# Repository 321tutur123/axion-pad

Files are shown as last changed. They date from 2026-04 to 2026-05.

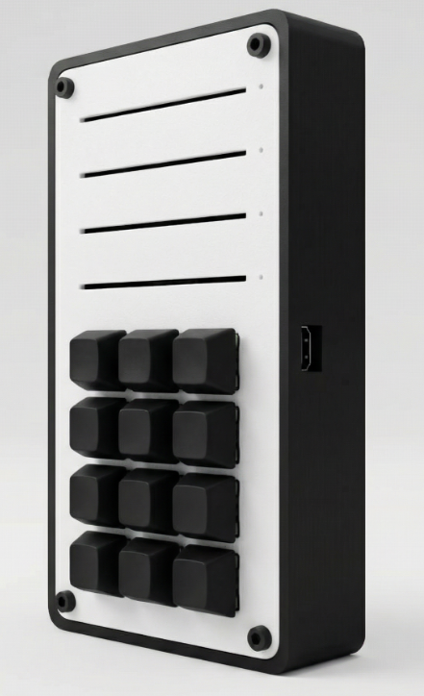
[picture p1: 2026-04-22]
assets/photos/vue du coté.png

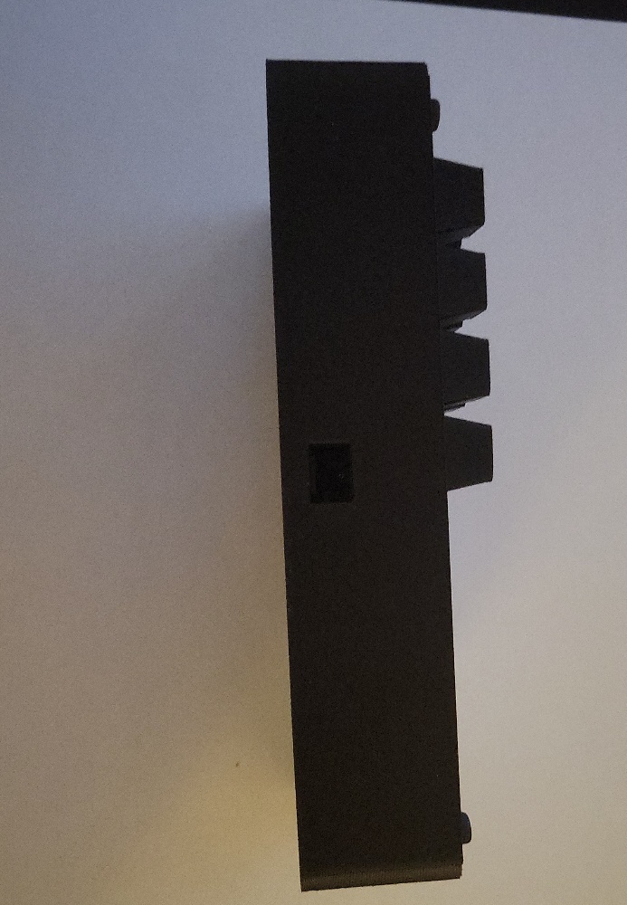
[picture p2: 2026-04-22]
assets/photos/derriere.jpg

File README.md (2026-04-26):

# AxionPad

**The macro pad built for creators, streamers, and power users.**  
Map macros, control audio, and fine-tune every detail — all from one device.

→ **[axionpad.fr](https://axionpad.fr)**

---

## The Product

AxionPad is a compact, programmable macro pad powered by an RP2040 microcontroller. It comes in three versions to match every setup:

| Model | Keys | Faders | RGB | OLED |
|---|---|---|---|---|
| **Mini** | 6 | — | Optional | — |
| **Standard** | 12 | 4 | Optional | — |
| **XL** | 16 | 6 | Optional | Yes|

All models ship with the **AxionPad Native** configurator for Windows.

---

## AxionPad Native — Configurator App

The desktop companion app lets you configure every key and fader without touching any code. Changes are pushed directly to the device over USB.

**Download:** [Latest Release](https://github.com/321tutur123/axion-pad/releases/latest) — Windows `.exe` installer

### Key features

- **Macro keys** — keyboard shortcuts, app launch, media controls, mute targets, AutoHotkey scripts
- **Audio faders** — per-process volume control via WASAPI (no virtual audio drivers needed)
- **RGB control** — per-key color and lighting effects
- **OLED display** (XL only) — live system stats or custom text
- **Presets** — Streaming, Gaming, Productivity, DAW — switch in one click
- **Live soundbar** — real-time visualization of fader values
- **System tray** — runs silently in the background, auto-starts with Windows
- **Direct flash** — exports `code.py` and writes it straight to the device's `CIRCUITPY` drive

---

## Repository Structure

```
axion-pad/
├── application/      Java/JavaFX configurator (Maven)
├── firmwares/
│   ├── MINI/         CircuitPython firmware — Mini
│   ├── STANDARD/     CircuitPython firmware — Standard
│   └── XL/           CircuitPython firmware — XL
├── hardware/
│   ├── pcb/          PCB schematics
│   └── cad/          3D models (STL / OBJ)
├── website/          Next.js landing page → axionpad.fr (Cloudflare Pages)
└── assets/           Brand assets (logos, photos)
```

---

## Tech Stack

| Layer | Technology |
|---|---|
| Microcontroller | RP2040 + CircuitPython |
| Desktop app | Java 17, JavaFX 21, Maven |
| Serial I/O | jSerialComm |
| Windows audio | WASAPI via JNA |
| Website | Next.js 15, Tailwind CSS |
| Hosting | Cloudflare Pages |
| CI/CD | GitHub Actions |

---

## Building from Source

### Prerequisites

- Java 17+
- Maven 3.8+

### Run in dev mode

```bash
cd application
mvn javafx:run
```

### Build Windows installer

```bash
cd application
scripts\build-windows.bat
# Output: dist/windows/AxionPadConfigurator.exe
```

---

## Website — Cloudflare Pages

Every push to `main` that touches `website/**` triggers an automatic deployment via GitHub Actions.

### Required secrets

| Secret | Description |
|---|---|
| `CLOUDFLARE_API_TOKEN` | API token with *Cloudflare Pages: Edit* permission |
| `CLOUDFLARE_ACCOUNT_ID` | Found in the Cloudflare dashboard sidebar |

---

## License

The configurator source code is released under the **MIT License**.  
The AxionPad name, logo, and hardware designs are proprietary — all rights reserved.

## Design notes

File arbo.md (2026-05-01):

# Arborescence du projet AxionPad

> Projet : macro pad programmable (RP2040 + CircuitPython) avec configurateur JavaFX et site e-commerce Next.js.

---

## Racine du projet

| Fichier | Rôle |
|---|---|
| `README.md` | Documentation principale : présentation du produit, versions (Mini/Standard/XL), stack technique, instructions de build |
| `.gitignore` | Fichiers et dossiers exclus du suivi Git |
| `RECAP_PROJET.txt` | Résumé global du projet |

## Maintenance updates for version 2.0.3:

### Dynamic Slider Support (DeviceModel.java, SliderConfig.java)
- Added full support for 6 sliders on XL model (GP0/A4 and GP1/A5 pins)
- Safe pin label access with bounds checking
- Improved Python/YAML export formatting with validation

### Audio Service Improvements (WindowsVolumeService.java)
- Enhanced process mute handling with .exe suffix enforcement
- Added special Discord mute case
- Throttled error logging to prevent spam
- Unified logging through DebugLogger

### Logging Refactor (KeysController.java, Main.java)
- Removed all debug() calls in favor of DebugLogger
- Added proper error handling around serial operations  
- Centralized logging configuration in DebugLogger
- Removed hardcoded temp file paths

### JSON Handling (OpenRgbServer.java)
- Added robust JSON validation and error handling
- Proper type checking for all input fields
- Input sanitization for RGB values
- Standardized error responses

### Build System (build-windows.bat, pom.xml)
- Version bumped to 2.0.3
- Fixed BOM encoding issues in build script
- Cleaned up debug artifacts
- Improved build reliability

### Documentation
- Updated all code documentation
- Standardized logging messages across services
- Added architecture notes for audio and RGB services
| `arbo.md` | Ce fichier — cartographie complète de l'arborescence |
| `axion-pad.*.log` | Log d'exécution de l'application (généré automatiquement) |
| `.aider.chat.history.md` | Historique de conversations avec l'IA Aider |
| `.aider.input.history` | Historique des commandes Aider |

---

## `.claude/` — Configuration Claude Code

| Fichier | Rôle |
|---|---|
| `settings.json` | Paramètres globaux Claude Code : serveur MCP filesystem, liste blanche de commandes (npm, git, bash) |
| `settings.local.json` | Surcharges locales non versionnées des paramètres Claude |

---

## `.github/workflows/` — CI/CD GitHub Actions

| Fichier | Rôle |
|---|---|
| `deploy.yml` | Pipeline de déploiement du site sur Cloudflare Pages (déclenché sur push dans `website/`, Node 22, `npm run pages:build`, wrangler-action) |
| `java-ci.yml` | Pipeline CI Java : compile et exécute les tests Maven (`mvn -B -q test`) sur Java 17 à chaque push/PR touchant `application/` |

---

## `application/` — Configurateur desktop JavaFX

Application de bureau Windows (Java 17 + JavaFX 21) qui permet de configurer le macro pad via USB série.

### Fichiers de build & config

| Fichier | Rôle |
|---|---|
| `pom.xml` | Fichier Maven : dépendances (JavaFX 21, jSerialComm, Gson, JNA), configuration du plugin jpackage pour générer le MSI |
| `build-windows.bat` | Script batch pour builder l'installeur MSI Windows |
| `build-unix.sh` | Script shell équivalent pour Linux/macOS |
| `icon.ico` | Icône de l'application |
| `CLAUDE.md` | Guide d'architecture interne pour Claude Code (pattern MVC, modèles matériels, flux de données) |
| `README.md` | Documentation technique détaillée : prérequis, connexion série, contrôle du volume, codes d'erreur, FAQ |
| `.claude/settings.local.json` | Surcharges Claude Code locales au sous-projet |

### `src/main/java/com/axionpad/` — Code source Java

#### Point d'entrée

| Fichier | Rôle |
|---|---|
| `Main.java` | Point d'entrée JVM ; initialise le logging vers `C:\temp\axionpad_debug.log` |
| `AxionPadApp.java` | Sous-classe `javafx.application.Application` ; démarre la fenêtre principale |
| `StartupRegistryHelper.java` | Interagit avec le registre Windows pour activer/désactiver le démarrage automatique au boot |

#### `view/` — Couche Vue (UI)

| Fichier | Rôle |
|---|---|
| `MainWindow.java` | Fenêtre racine : StackPane avec routing de navigation, sidebar, badge du modèle détecté |
| `PortDialog.java` | Dialogue de sélection du port série USB |

#### `controller/` — Couche Contrôleur (gestion des pages)

| Fichier | Rôle |
|---|---|
| `Controllers.java` | Registre central de tous les contrôleurs |
| `KeysController.java` | Grille de touches (6/12/16 selon le modèle) ; panneau de configuration par touche (ActionType : KEYBOARD, APP, MUTE, MEDIA, AHK) ; UI des modificateurs et raccourcis |
| `SlidersController.java` | Mapping des potentiomètres (0/4/6 canaux selon le modèle) ; noms des processus pour le contrôle du volume par application |
| `SoundbarController.java` | Visualisation en temps réel des niveaux sonores via `ProgressBar` |
| `RgbController.java` | Contrôle des LEDs RGB (effets : OFF/STATIC/BREATHING/WAVE, color pickers, vitesse, luminosité) — Standard/XL uniquement |
| `ExportController.java` | Affiche le code `code.py` généré pour le firmware ; fonctions copier/enregistrer |
| `SimulatorController.java` | Simulateur logiciel du périphérique (sans matériel réel) |
| `SettingsController.java` | Panneau des préférences de l'application |
| `PresetService.java` | Gestionnaire de presets intégrés (Streaming, Gaming, Productivité, MAO) |

#### `model/` — Couche Modèle (données)

| Fichier | Rôle |
|---|---|
| `DeviceModel.java` | Enum des modèles matériels : MINI (6 touches), STANDARD (12 touches + 4 pots), XL (16 touches + 6 pots + OLED). Auto-détecté depuis le greeting firmware |
| `KeyConfig.java` | Configuration d'une touche individuelle : ActionType, modificateurs, code touche, chemin d'application |
| `SliderConfig.java` | Configuration d'un canal potentiomètre : nom du processus, plage de volume |
| `RgbConfig.java` | Paramètres RGB : type d'effet, couleur1, couleur2, luminosité, vitesse |
| `PadConfig.java` | Configuration complète du pad : nom de profil, liste de layers, tableau sliders, config RGB. Rétrocompatible v1 |
| `AppSettings.java` | Paramètres applicatifs (démarrage auto, langue, etc.) |

#### `service/` — Couche Service (logique métier & matériel)

| Fichier | Rôle |
|---|---|
| `SerialService.java` | Gestion du port série via jSerialComm : auto-détection, détection du modèle depuis le greeting firmware, watchdog 5 s, basculement mode POLL selon minimisation de l'UI |
| `ConfigService.java` | Persistance JSON dans `~/.axionpad/config.json` ; migration rétrocompatible depuis la v1 |
| `WindowsVolumeService.java` | Contrôle audio WASAPI/COM via JNA sur thread STA dédié ; throttle à 20 Hz ; volume par application |
| `RgbService.java` | Persistance des effets LED et génération des commandes série (format `RGB:STATIC:r,g,b`) |
| `OledService.java` | Gestion de l'afficheur OLED du modèle XL : synchronisation RTC + stats périodiques CPU/RAM/heure toutes les 2 s |
| `OpenRgbServer.java` | Serveur HTTP REST sur `127.0.0.1:7742` pour l'intégration SignalRGB/OpenRGB ; CORS activé ; pool de threads asynchrone |
| `KeyHookService.java` | Enregistrement du hook clavier global Windows (capture bas niveau des touches) |
| `HardwareMonitorService.java` | Stats CPU/RAM via MXBean ; GPU/température stubés (nécessite OSHI/NVML) |
| `InventoryService.java` | Suivi de l'inventaire matériel |
| `AppLauncherService.java` | Lancement d'exécutables applicatifs |
| `SettingsService.java` | Persistance et récupération des paramètres |
| `I18n.java` | Chaînes d'internationalisation/localisation |
| `DebugLogger.java` | Logging vers `%APPDATA%/AxionPad/debug.log` |

### `src/main/resources/com/axionpad/`

| Chemin | Rôle |
|---|---|
| `css/dark.css` | Feuille de style unique — thème sombre de l'application |
| `firmware/code.py` | Copie embarquée du firmware STANDARD pour l'export in-app |
| `icons/axionpad_tray.png` | Icône de la barre système (tray) |
| `icons/icon.ico` | Icône de fenêtre |
| `icons/logo1.png` | Logo de l'application |

### `src/test/java/com/axionpad/model/` — Tests unitaires

| Fichier | Rôle |
|---|---|
| `DeviceModelTest.java` | Tests du modèle matériel (enum DeviceModel) |
| `PadConfigTest.java` | Tests de l'objet de configuration (sérialisation, migration v1→v2) |
| `SliderConfigTest.java` | Tests de la configuration des potentiomètres |

### `dist/` — Installeurs distribués

| Fichier | Rôle |
|---|---|
| `AxionPad-2.0.1.msi` | Installeur MSI version actuelle |
| `AxionPad-2.0.0.msi` | Version précédente |
| `AxionPad-1.0.1.msi` | Version legacy |
| `AxionPad-1.0.msi` | Version originale |

---

## `firmwares/` — Firmware CircuitPython (3 variantes)

Chaque variante émet un greeting `AXIONPAD:[MODELE]` au démarrage pour l'auto-détection par le configurateur.

| Fichier | Rôle |
|---|---|
| `MINI/code.py` | Firmware 6 touches (2×3), sans RGB ni OLED |
| `STANDARD/code.py` | Firmware 12 touches (3×4), 4 potentiomètres, LEDs RGB NeoPixel |
| `XL/code.py` | Firmware 16 touches (4×4), 6 potentiomètres, RGB NeoPixel, écran OLED SSD1306, module RTC |

**Protocole série :**
- Sortie : `"val1|val2|val3|val4\n"` pour les valeurs des sliders
- Entrée : `RGB:STATIC:r,g,b` · `POLL:LOW/HIGH` · `OLED[:CPU:XX][:RAM:XX][:HHMM:XXXX]`

---

## `hardware/` — Fichiers de conception matérielle

### `hardware/cad/body/` — Boîtier

| Fichier | Rôle |
|---|---|
| `Body_certo.SLDPRT` / `.STL` | Corps principal du boîtier (SolidWorks + export STL pour impression 3D) |
| `Top_Case_.SLDPRT` / `.STL` | Couvercle supérieur |
| `body axion v5.f3z` | Boîtier version 5 (Fusion 360) |
| `body axion v4.3.3mf` / `body axion.3mf` | Boîtier en format 3MF (impression 3D) |
| `v_perso axion.3mf` | Variante personnalisée |
| `alignement des touches v*.stl` | Gabarits d'alignement des touches (v1 et v2) |
| `dessus slider.stl` | Dessus du slider |
| `tentative bras.stl` | Tentative de conception d'un bras de maintien |

### `hardware/cad/components/` — Modèles de composants

| Fichier | Rôle |
|---|---|
| `cherry_mx_switch.step` | Modèle 3D d'un switch Cherry MX |
| `cherry_mx_keycap.*` | Keycap Cherry MX (STL + OBJ) |
| `fader_knob.*` | Bouton de fader (STL + OBJ) |
| `knob.*` | Bouton rotatif (STEP + 3MF) |
| `screw_chc_m3_l14.*` | Vis CHC M3 L14 (STEP + OBJ + MTL) |

### `hardware/cad/exports/` — Assemblages exportés

| Dossier | Rôle |
|---|---|
| `assembly_2026-03-27/` | Export d'assemblage PCB + composants (format OBJ/MTL, mars 2026) |
| `assembly_2026-04-21/` | Export complet récent (avril 2026) : PCB, corps, fond, couvercle, switches |

### `hardware/pcb/` — PCB

| Fichier | Rôle |
|---|---|
| `axion_v1_pcb.step` / `.stp` | Modèle 3D du PCB (dernière révision) |
| `gerber.zip` | Fichiers Gerber pour la fabrication du PCB |

### `hardware/mcu/microcontrolleur/` — Microcontrôleur

| Fichier | Rôle |
|---|---|
| `BOM_AS2040.xlsx` | Liste des composants (Bill of Materials) pour l'AS2040 (alternative RP2040) |
| `PickAndPlace_PCB_AS2040-copy_2026-02-25.csv` | Coordonnées de placement pour l'assemblage automatique |
| `as2040.json` | Spécifications du composant |

### `hardware/obj/` — Exports 3D PCB

| Fichier | Rôle |
|---|---|
| `OBJ_PCB_AXION_V1_PCB_2.obj` / `.mtl` | Modèle 3D du PCB en format OBJ avec matériaux |

### `hardware/top/` — Plaque supérieure

| Fichier | Rôle |
|---|---|
| `pieces/Grand Jaiks-Jarv/` | Variante de design de plaque supérieure |
| `pieces/ImageToStl.com_tinker.zip` | Conversion image vers STL |
| `pieces/top.zip` | Design consolidé de la plaque supérieure |

---

## `website/` — Site e-commerce Next.js (axionpad.fr)

### Fichiers de config & build

| Fichier | Rôle |
|---|---|
| `package.json` | Dépendances npm : Next.js 15.5, React 19, TypeScript, GSAP, Three.js, React Three Fiber, Zustand, Stripe, Tailwind CSS |
| `package-lock.json` | Versions exactes verrouillées des dépendances |
| `next.config.ts` | Configuration Next.js (output, redirects, etc.) |
| `tsconfig.json` | Configuration TypeScript |
| `postcss.config.mjs` | PostCSS pour Tailwind CSS |
| `eslint.config.mjs` | Règles ESLint |
| `.env.local` | Variables d'environnement locales (clés Stripe, D1, secrets — non versionné) |
| `wrangler.toml` | Configuration Cloudflare Workers/Pages (binding D1, nom du projet) |
| `.vercel/project.json` | Métadonnées Vercel (legacy, migration vers Cloudflare Pages effectuée) |
| `CLAUDE.md` | Redirige vers `AGENTS.md` |
| `AGENTS.md` | Avertissements sur les différences de version Next.js et les breaking changes |

### `migrations/` — Schémas base de données Cloudflare D1

| Fichier | Rôle |
|---|---|
| `0001_orders.sql` | Schéma de la table des commandes |
| `0002_reviews.sql` | Schéma de la table des avis produits |
| `0003_add_tracking.sql` | Ajout du suivi de commande |
| `0004_idempotency.sql` | Clés d'idempotence pour éviter les doublons de paiement |

### `public/` — Assets statiques

| Fichier | Rôle |
|---|---|
| `models/axionpad.glb` | Modèle 3D du produit en glTF binaire (utilisé dans le viewer 3D du site) |
| `images/products/` | Dossier des photos produits (placeholder `.gitkeep`) |
| `*.svg` | Icônes SVG génériques (file, globe, window, next, vercel) |

### `src/app/` — Pages & routes Next.js (App Router)

| Fichier/Dossier | Rôle |
|---|---|
| `page.tsx` | Page d'accueil : scène 3D avec scroll storytelling (300vh), animations GSAP ScrollTrigger |
| `layout.tsx` | Layout racine : providers, police, métadonnées globales |
| `globals.css` | Styles CSS globaux |
| `favicon.ico` | Favicon du site |
| `shop/page.tsx` | Page liste des produits |
| `shop/[slug]/page.tsx` | Page détail produit dynamique avec viewer 3D |
| `shop/[slug]/ProductConfigurator.tsx` | Composant configurateur interactif du produit |
| `login/page.tsx` | Page de connexion utilisateur |
| `register/page.tsx` | Page d'inscription |
| `cart/page.tsx` | Page panier |
| `checkout/page.tsx` | Formulaire de paiement |
| `success/page.tsx` | Page de confirmation de commande |
| `track/page.tsx` | Suivi de commande |
| `about/page.tsx` | Page à propos |
| `software/page.tsx` | Page du logiciel configurateur |
| `cgv/page.tsx` | Conditions Générales de Vente |
| `confidentialite/page.tsx` | Politique de confidentialité |
| `mentions-legales/page.tsx` | Mentions légales |
| `components/[slug]/page.tsx` | Page de présentation dynamique d'un composant matériel |

### `src/app/api/` — Routes API Next.js

| Route | Rôle |
|---|---|
| `auth/login/route.ts` | Endpoint de connexion utilisateur |
| `auth/register/route.ts` | Endpoint d'inscription utilisateur |
| `admin/login/route.ts` | Authentification admin |
| `admin/orders/route.ts` | Liste et gestion des commandes (admin) |
| `admin/orders/[id]/route.ts` | Détail et mise à jour d'une commande individuelle |
| `checkout/route.ts` | Création d'une session Stripe Checkout |
| `reviews/route.ts` | Soumission et récupération des avis produits |
| `track/route.ts` | API de suivi de commande |
| `webhook/route.ts` | Gestionnaire de webhooks Stripe (événements de paiement) |

### `src/components/` — Composants React réutilisables

| Fichier | Rôle |
|---|---|
| `3d/Scene.tsx` | Setup de la scène Three.js de base |
| `3d/HeroScene.tsx` | Scène 3D de la section hero |
| `3d/ScrollScene.tsx` | Scène 3D pilotée par le scroll |
| `3d/ProductModel.tsx` | Viewer 3D du produit (chargement du fichier `.glb`) |
| `3d/FloatingParticles.tsx` | Effet de particules flottantes |
| `3d/ModelErrorBoundary.tsx` | Error boundary pour les erreurs de rendu 3D |
| `layout/Navbar.tsx` | Barre de navigation : icône panier, liens auth |
| `layout/Footer.tsx` | Pied de page |
| `CheckoutButton.tsx` | Bouton de paiement Stripe |
| `ProductImage.tsx` | Image produit avec fallback |
| `ReviewSection.tsx` | Section d'affichage des avis clients |
| `animations/ScrollReveal.tsx` | Animations d'apparition au scroll |

### `src/data/`, `src/types/`, `src/hooks/`, `src/lib/`, `src/store/`

| Fichier | Rôle |
|---|---|
| `data/products.json` | Catalogue produits (noms, descriptions, prix, modèles) |
| `types/index.ts` | Définitions des types TypeScript partagés |
| `env.d.ts` | Types des variables d'environnement |
| `hooks/useScrollAnimation.ts` | Hook personnalisé pour les animations basées sur le scroll |
| `lib/gsap.ts` | Wrapper GSAP et initialisation de ScrollTrigger |
| `lib/three.ts` | Utilitaires Three.js |
| `lib/scrollProgress.ts` | Tracking de la progression du scroll |
| `lib/products-data.ts` | Utilitaires de données produits |
| `lib/components-data.ts` | Données des composants matériels présentés sur le site |
| `lib/api.ts` | Client API (fetch helpers) |
| `lib/user-auth.ts` | Utilitaires d'authentification utilisateur |
| `lib/admin-auth.ts` | Utilitaires d'authentification admin |
| `store/cart.ts` | Store Zustand du panier : add / remove / clear |

---

## `assets/` — Assets de marque & marketing

### `assets/logos/`

| Fichier | Rôle |
|---|---|
| `colored-logo.png/svg/pdf` | Logo AxionPad coloré (3 formats) |
| `transparent-logo.png/svg/pdf` | Logo avec fond transparent (3 formats) |
| `logo.png`, `logo1.png`, `logo2.png` | Variantes du logo |
| `Vista Logos.zip` | Pack de logos Vista |

### `assets/photos/`

| Fichier | Rôle |
|---|---|
| `vue dessus.png` | Photo du produit vue de dessus |
| `vue du coté.png` | Photo vue de côté |
| `derriere.jpg` | Photo vue de derrière |
| `image large.jpg` | Grande photo produit (marketing) |

---

## `_deprecated_root/` — Ancienne version du site (archivé)

Contient l'itération précédente du site web avant la migration vers `/website/`. Même structure que le site actuel mais **ne plus maintenée**. Conservé uniquement pour référence historique. Inclut `frontend/node_modules/` (~8000+ fichiers) et les artefacts de build `.next/`.

---

## Stack technologique résumée

| Couche | Technologie |
|---|---|
| Firmware | CircuitPython (RP2040) |
| Configurateur desktop | Java 17, JavaFX 21, Maven, jSerialComm, JNA, Gson |
| Site web | Next.js 15, React 19, TypeScript, Tailwind CSS |
| 3D web | Three.js, React Three Fiber, GSAP |
| État global web | Zustand |
| Paiement | Stripe |
| Base de données | Cloudflare D1 (SQLite) |
| Hébergement | Cloudflare Pages |
| CI/CD | GitHub Actions |
| Conception matérielle | SolidWorks, Fusion 360, KiCad (Gerber) |

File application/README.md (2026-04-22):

# AXION PAD
**Configurateur RP2040 · CircuitPython**
*Documentation Technique & Guide de Débogage*
*Version 1.0 — Avril 2026*

---

## Table des matières
1. [Présentation du système](#1-présentation-du-système)
2. [Prérequis & Installation](#2-prérequis--installation)
3. [Architecture logicielle](#3-architecture-logicielle)
4. [Connexion série (port COM)](#4-connexion-série-port-com)
5. [Contrôle du volume (NirCmd)](#5-contrôle-du-volume-nircmd)
6. [Guide de débogage complet](#6-guide-de-débogage-complet)
7. [Codes d'erreur & solutions](#7-codes-derreur--solutions)
8. [FAQ](#8-faq)

---

## 1. Présentation du système
L'Axion Pad est un contrôleur physique USB basé sur un microcontrôleur RP2040 programmé en CircuitPython. Il se connecte à un PC via USB et communique avec le logiciel Axion Pad Configurator pour piloter le volume des applications Windows et envoyer des raccourcis clavier.

### Composants matériels

| Composant | Description |
| :--- | :--- |
| **Microcontrôleur** | RP2040 (Raspberry Pi Pico ou compatible) |
| **Firmware** | CircuitPython — exécute code.py au démarrage |
| **12 touches** | Boutons poussoirs — envoient F13 à F24 ou raccourcis configurés |
| **4 potentiomètres** | Envoi de valeurs 0–1023 via port série pour contrôle du volume |
| **Interface USB** | Apparaît comme port COM (CDC Serial) sous Windows |

### Flux de données
Le pad envoie en continu sur le port série les valeurs des 4 potentiomètres sous le format :
> `512|489|1023|0` (séparateur : `|` ou `,` ou `;`)

Le logiciel lit ces valeurs, les convertit en pourcentage (0–100%) et les transmet à NirCmd pour ajuster le volume des applications Windows correspondantes.

---

## 2. Prérequis & Installation

### Logiciels requis

| Logiciel | Version minimale | Rôle |
| :--- | :--- | :--- |
| **Java (JDK)** | 17 (Eclipse Adoptium) | Exécution du configurateur |
| **NirCmd** | 2.86+ | Contrôle du volume Windows |
| **CircuitPython** | 8.x ou 9.x | Firmware du pad |
| **Windows** | 10 ou 11 | Système d'exploitation |

### Installation de NirCmd (OBLIGATOIRE)

> **⚠ Attention** : NirCmd doit être installé sur CHAQUE PC utilisant l'Axion Pad. Sans lui, le contrôle du volume est non fonctionnel.

* Télécharger NirCmd depuis : `https://www.nirsoft.net/utils/nircmd.html` (version 64-bit).
* Extraire `nircmd.exe`.
* Copier `nircmd.exe` dans `C:\Windows\System32\`.
* Vérifier en PowerShell : `nircmd.exe setsysvolume 32767`.

Le volume master doit passer à 50% si NirCmd est correctement installé.

---

## 3. Architecture logicielle

### Structure des fichiers

| Fichier | Rôle |
| :--- | :--- |
| `Main.java` | Point d'entrée de l'application JavaFX |
| `view/MainWindow.java` | Fenêtre principale — titlebar, sidebar, routing des pages |
| `view/PortDialog.java` | Dialogue de sélection du port série COM |
| `service/SerialService.java` | Connexion et lecture série — thread dédié, callbacks |
| `service/VolumeService.java` | Appel NirCmd pour contrôle du volume par application |
| `service/ConfigService.java` | Lecture/écriture de la configuration JSON sur disque |
| `controller/KeysController.java` | Interface de configuration des 12 touches |
| `controller/SlidersController.java` | Interface de configuration des 4 potentiomètres |
| `controller/SoundbarController.java` | Affichage temps réel des niveaux de volume |
| `controller/SimulatorController.java` | Simulation du pad sans matériel physique |
| `resources/css/dark.css` | Thème visuel sombre de l'interface JavaFX |

---

## 4. Connexion série (port COM)

### Fonctionnement
L'Axion Pad apparaît sous Windows comme un port COM série (CDC). Le logiciel utilise la bibliothèque jSerialComm pour détecter et lire ce port. La détection automatique cherche les mots-clés suivants dans le nom du port :
* `circuitpython`, `rp2040`, `circuit`, `adafruit`, `usb serial`
* `usbmodem`, `cu.usbmodem`

Si aucun port correspondant n'est trouvé, le premier port COM disponible est présélectionné.

### Paramètres de connexion

| Paramètre | Valeur |
| :--- | :--- |
| **Baud rate** | 115200 |
| **Bits de données** | 8 |
| **Bits de stop** | 1 |
| **Parité** | Aucune |
| **Timeout lecture** | 2000 ms (semi-bloquant) |

---

## 5. Contrôle du volume (NirCmd)

### Principe
Chaque potentiomètre est associé à un "canal" (nom de processus Windows). Quand le pad envoie une valeur, le logiciel appelle NirCmd pour ajuster le volume de l'application correspondante.

### Canaux spéciaux

| Canal | Comportement |
| :--- | :--- |
| `master` | Volume master Windows (tous les sons) |
| `mic` / `default_record` | Volume du microphone / périphérique d'enregistrement par défaut |
| `discord.exe` | Volume de Discord spécifiquement |
| `spotify.exe` | Volume de Spotify spécifiquement |
| `system` | Sons système Windows |

### Limitation de débit
Pour éviter de surcharger NirCmd, les appels sont limités à 1 toutes les 100 ms (10 fois/seconde maximum), quelle que soit la fréquence d'envoi du pad.

---

## 6. Guide de débogage complet

### Problème : Le volume ne change pas

**Étape 1 — Vérifier NirCmd**
* Ouvrir PowerShell et taper :
    * `where.exe nircmd.exe`
* Si aucun résultat : NirCmd n'est pas installé. Voir section 2.
* Si trouvé, tester manuellement :
    * `nircmd.exe setsysvolume 32767`
* Le volume master doit passer à 50%. Sinon NirCmd est corrompu — le réinstaller.

**Étape 2 — Vérifier que le pad est bien connecté**
* Dans le logiciel, le bouton en haut à droite doit afficher "Axion Pad connecté".
* Si ce n'est pas le cas, cliquer sur "Connecter le pad" et sélectionner le bon port COM.

**Étape 3 — Vérifier le bon canal dans la configuration**
* Ouvrir l'onglet "Potentiomètres". Vérifier que le canal correspond bien au nom du processus de l'application cible. Exemples :
    * `discord.exe` — `spotify.exe` — `chrome.exe` — `master`

> **💡 Conseil** : Pour trouver le nom exact d'un processus : ouvrir le Gestionnaire des tâches > onglet Détails. Le nom affiché dans la colonne "Nom" est celui à utiliser.

### Problème : Le pad n'est pas détecté
**Vérifications à effectuer :**
* Débrancher et rebrancher le câble USB.
* Vérifier que le câble est bien un câble DATA (pas uniquement alimentation).
* Dans le Gestionnaire de périphériques Windows, vérifier qu'un port COM apparaît.
* Si le port apparaît avec un triangle jaune : installer les drivers CP210x ou CH340 selon la puce USB du pad.
* Réessayer en branchant sur un port USB directement sur la carte mère (pas un hub).

### Problème : L'application plante au démarrage
* Vérifier que Java 17 ou supérieur est installé :
    * `java -version`
* Si absent : télécharger Eclipse Adoptium JDK 17 sur `https://adoptium.net`.

### Problème : Une fenêtre NirCmd s'ouvre en boucle

> **⚠ Critique** : Ce problème indique que NirCmd reçoit des arguments incorrects. Forcer l'arrêt immédiatement avec ces commandes PowerShell :
> * `taskkill /F /IM nircmd.exe`
> * `taskkill /F /IM java.exe`

Puis réinstaller la dernière version du logiciel Axion Pad Configurator.

---

## 7. Codes d'erreur & solutions

| Message d'erreur | Solution |
| :--- | :--- |
| **Connexion impossible — Impossible d'ouvrir le port** | Le pad est débranché ou un autre logiciel utilise le port COM. Débrancher/rebrancher le pad. |
| **Erreur driver série — jSerialComm n'a pas pu charger** | Relancer le logiciel en tant qu'administrateur (clic droit > Exécuter en tant qu'administrateur). |
| **NirCmd introuvable** | Installer NirCmd et copier nircmd.exe dans C:\Windows\System32\. Voir section 2. |
| **Connexion perdue** | Le pad a été débranché pendant l'utilisation. Rebrancher et reconnecter via le bouton en haut à droite. |
| **Erreur lecture: null** | Timeout série. Vérifier le câble USB et réessayer. Un câble de mauvaise qualité peut causer des coupures. |
| **[Serial] Volume apply error** | NirCmd a retourné une erreur. Vérifier que le nom du processus dans la configuration est correct. |

---

## 8. FAQ

**Le pad fonctionne-t-il sur macOS / Linux ?**
Le matériel (RP2040 + CircuitPython) est compatible macOS et Linux. Cependant, `VolumeService.java` utilise NirCmd qui est exclusivement Windows. Sur macOS/Linux, le contrôle du volume nécessiterait une adaptation du code pour utiliser des outils natifs (AppleScript sur macOS, pactl sur Linux).

**Puis-je utiliser plusieurs pads simultanément ?**
Non, le logiciel ne gère qu'une seule connexion série à la fois. Pour supporter plusieurs pads, il faudrait modifier `SerialService` pour gérer plusieurs ports en parallèle.

**Comment réinitialiser la configuration ?**
Supprimer le fichier `AxionPad.cfg` situé dans le dossier du logiciel. Au prochain démarrage, une configuration par défaut sera recréée.

**Les touches F13–F24 ne font rien dans mon jeu ?**
Ces touches sont envoyées au système mais l'application cible doit les reconnaître. Pour les jeux, utiliser PowerToys Keyboard Manager ou AutoHotkey pour remapper F13–F24 vers des touches standard.

**Comment mettre à jour le firmware du pad ?**
* Brancher le pad en maintenant le bouton BOOTSEL enfoncé.
* Le pad apparaît comme un lecteur USB nommé `RPI-RP2`.
* Copier le nouveau fichier `code.py` (généré depuis l'onglet Export) à la racine du lecteur CIRCUITPY.
* Le pad redémarre automatiquement avec le nouveau firmware.

---
*Axion Pad Configurator — Document fourni avec le produit*
*Pour toute assistance, fournir ce document avec la description du problème rencontré.*

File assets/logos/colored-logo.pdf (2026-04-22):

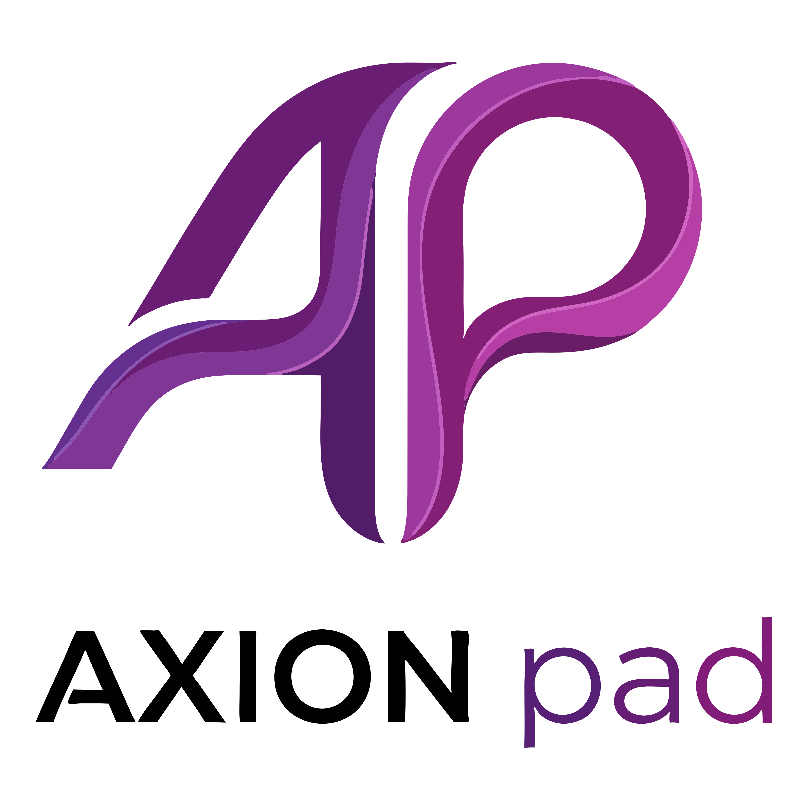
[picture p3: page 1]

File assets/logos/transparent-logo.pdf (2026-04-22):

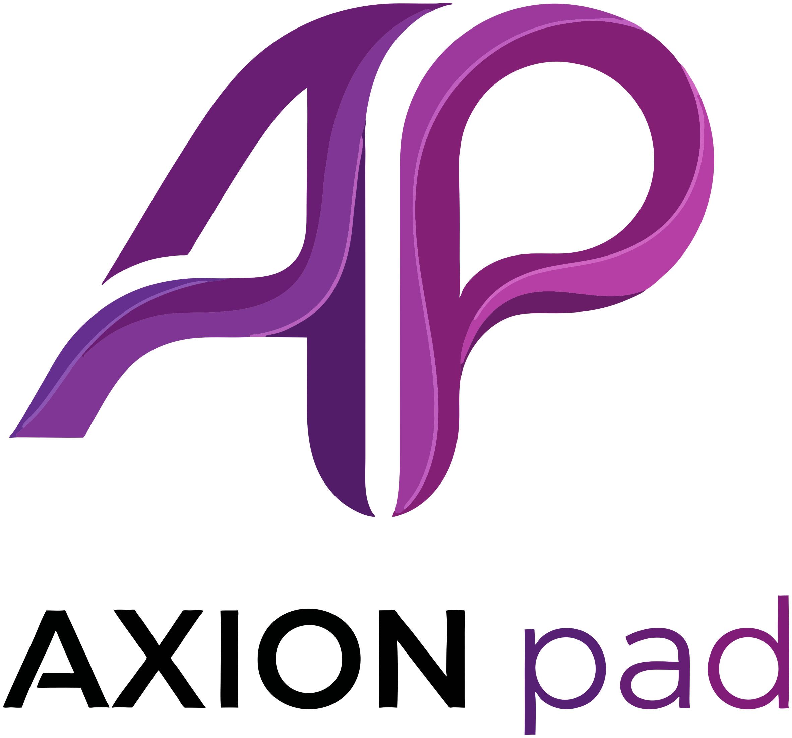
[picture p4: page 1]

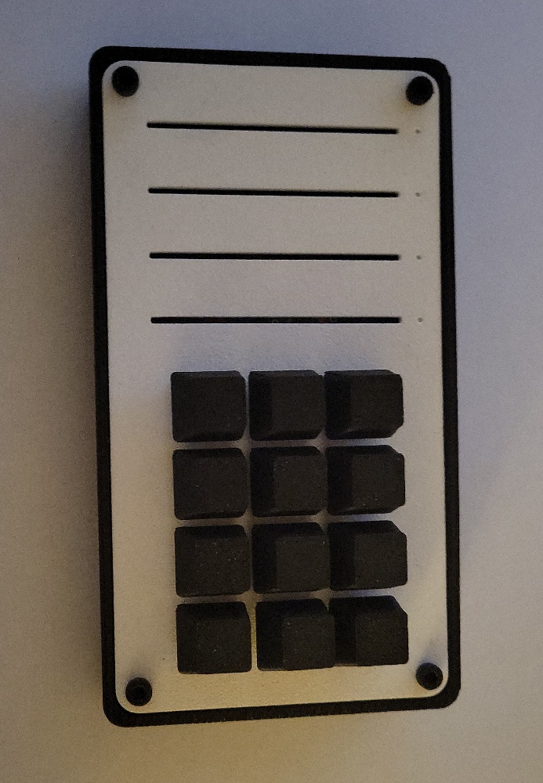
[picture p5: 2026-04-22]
assets/photos/image large.jpg

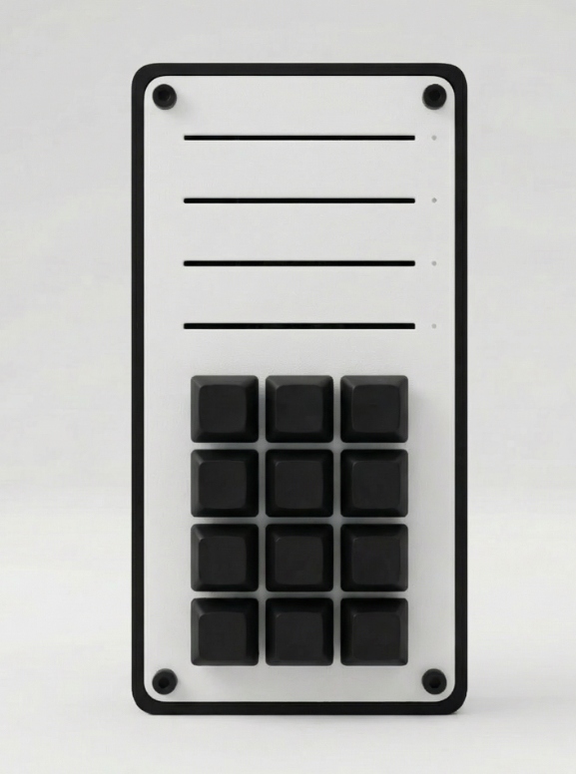
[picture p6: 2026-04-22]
assets/photos/vue dessus.png

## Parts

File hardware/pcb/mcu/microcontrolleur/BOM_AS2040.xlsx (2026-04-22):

ID | Name | Designator | Footprint | Quantity
1 | 4pF | C2,C3 | C0402 | 2
2 | 100nF | C5,C6,C7,C9,C11,C12,C13,C14,C15 | C0402 | 9
3 | 1uF | C8,C10 | C0402 | 2
4 | NSR0320MW2T1G | D3 | SOD-323_L1.8-W1.3-LS2.5-RD | 1
5 | TC2020RGB-3CJH-TX1812Z5 | LED2 | LED-SMD_4P-L2.1-W2.1-TL_TC2020RGB | 1
6 | 1K | R1,R5 | R0402 | 2
7 | 10K | R2,R8 | R0402 | 2
8 | 27 | R3,R4 | R0402 | 2
9 | 5.1K | R9,R10 | R0402 | 2
10 | GT-TC032A-H015-L1 | SW1,SW2 | SW-SMD_L3.1-W2.5-LS4.0 | 2
11 | RP2040 | U1 | LQFN-56_L7.0-W7.0-P0.4-EP | 1
12 | W25Q128JVPIQ | U2 | WSON-8_L5.0-W6.0-P1.27-BL-EP | 1
13 | 12MHz | X1 | OSC-SMD_4P-L3.2-W2.5-BL | 1
14 | 1uF | C1,C4 | C0402 | 2
15 | 10uF | C19 | C0402 | 1
16 | NSR0320MW2T1G | D1,D2 | SOD-323_L1.8-W1.3-LS2.5-RD | 2
17 | OSG50402C1C | LED1 | LED0402-RD_GREEN | 1
18 | XL-1005UGC | LED3 | LED0R | 1
19 | 100K | R11 | R0402 | 1
20 | 5.1K | R12,R13,R14 | R0402 | 3
21 | AP2112K-3.3TRG1 | U6 | SOT-25-5_L3.0-W1.8-P0.95-LS3.0-BR | 1
22 | MCP73831T-2ACI/OT | U8 | SOT-23-5_L3.0-W1.7-P0.95-LS2.8-BR | 1
23 | HDR_CON_TH_1x11_2.54 | J1,J2 | HDR_CON_TH_1X11_2.54 | 2
24 | 5.1K | R6,R7 | R0402 | 2
25 | SWD-10_SMD | SWD1 | SWD-10-SMD | 1
26 | USB3.1C16PFSMT | USBC1 | USB-C-SMD_TYPE-C-USB-17 | 1
27 | STEMMA_I2C_QT | CONN1 | JST_SH4 | 1
28 | 100nF | C17,C18 | C0402 | 2
29 | LSM6DSRTR | U4 | LGA-14_L3.0-W2.5-P0.50-BR | 1

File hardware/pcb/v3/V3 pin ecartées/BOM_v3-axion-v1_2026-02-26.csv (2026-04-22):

ID | Name | Designator | Footprint | Quantity | Manufacturer Part | Manufacturer | Supplier | Supplier Part | Price
1 | 1N4148S | D1BIS,D2BIS,D3BIS,D4,D5,D6,D7,D8,D9,D10,D11,D12 | DO-34_BD1.6-L3.0-P7.00-D0.6-RD | 12 | 1N4148S | GOOD-ARK(固锝) | LCSC | C179555 | 0.011
2 | RDC1047A03 | R15,R16,R17,R18 | RES-ADJ_TH_RDC1047A03 | 4 | RDC1047A03 | ALPSALPINE(阿尔卑斯阿尔派) | LCSC | C470676 | 2.036
3 | CPG135001D01 | SW1BIS,SW2BIS,SW3,SW4,SW5,SW6,SW7,SW8,SW9,SW10,SW11,SW12 | KEY-TH_CPG135001D0X | 12 | CPG135001D01 | Kailh(凯华) | LCSC | C400229 | 1.335
4 | HC-PM254-5.0H-1X9PZ | U1,U4 | CONN-TH_HC-PM254-5.0H-1X9PZ | 2 | HC-PM254-5.0H-1x9PZ | HC(虹成电子) | LCSC | C27985234 | 0.154

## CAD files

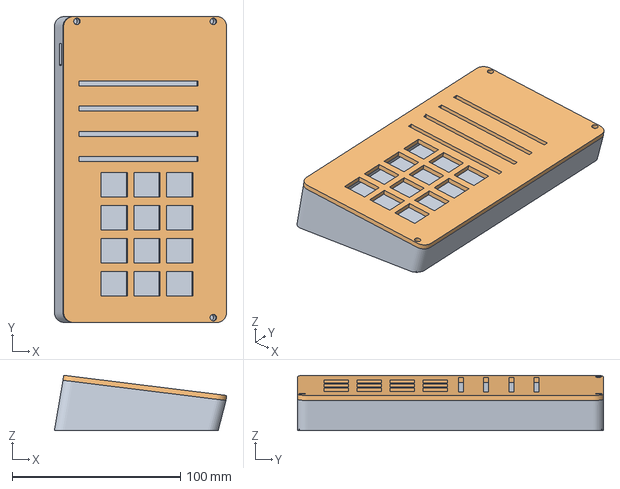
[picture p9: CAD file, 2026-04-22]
hardware/cad/body/body axion.3mf
102.5 x 182.0 x 33.0 mm
Corps1
Corps3

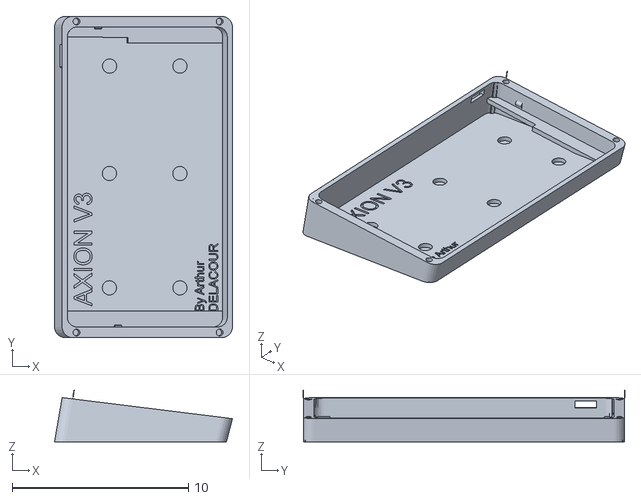
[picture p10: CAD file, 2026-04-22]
hardware/cad/exports/assembly_2026-04-21/body axion.obj
10.1 x 18.2 x 2.93

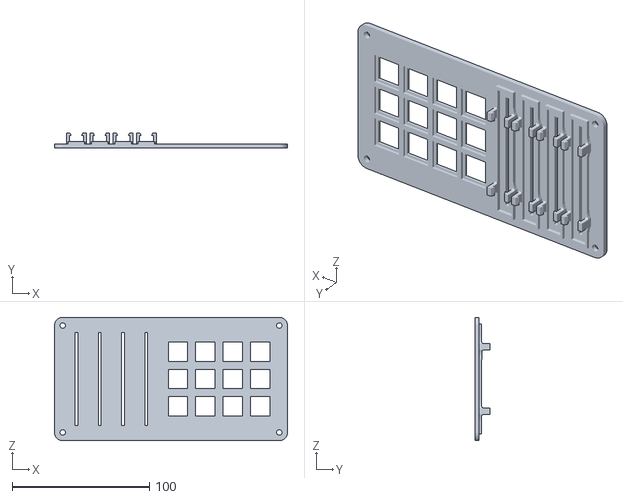
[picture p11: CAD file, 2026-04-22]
hardware/cad/top/pieces/Grand Jaiks-Jarv/tinker.obj
170.0 x 11.2 x 90.0

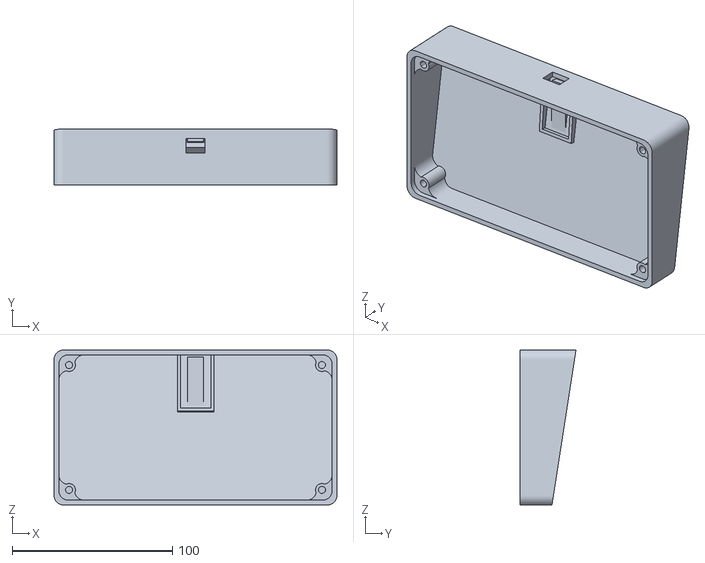
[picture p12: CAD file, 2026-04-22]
hardware/cad/top/pieces/tinker.obj
176.8 x 35.0 x 96.8

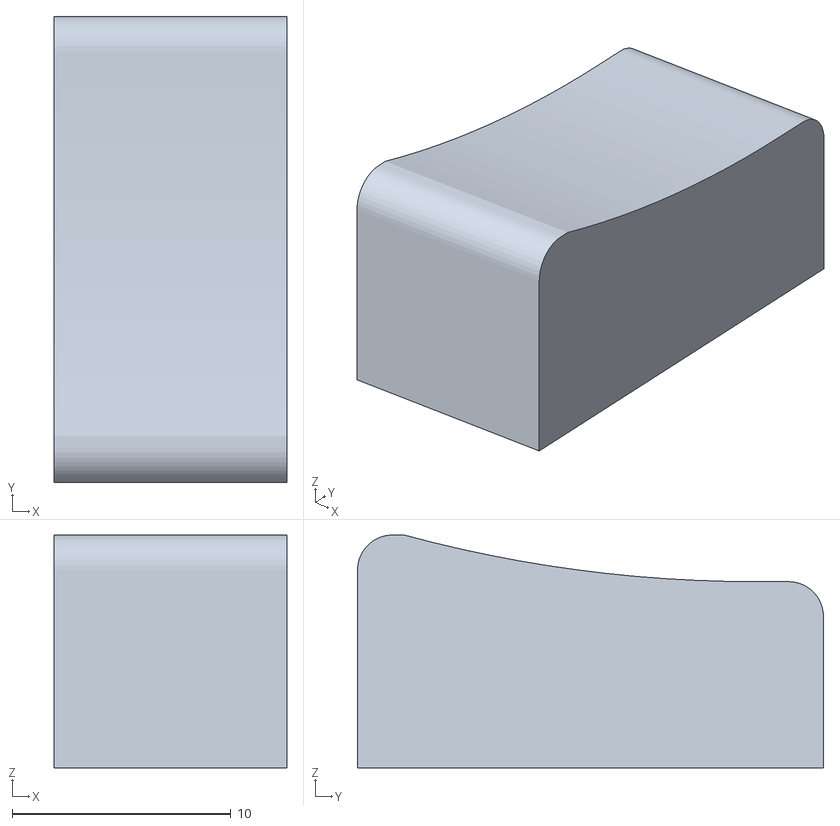
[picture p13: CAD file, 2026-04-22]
hardware/cad/body/dessus slider.stl
10.6 x 21.3 x 10.6

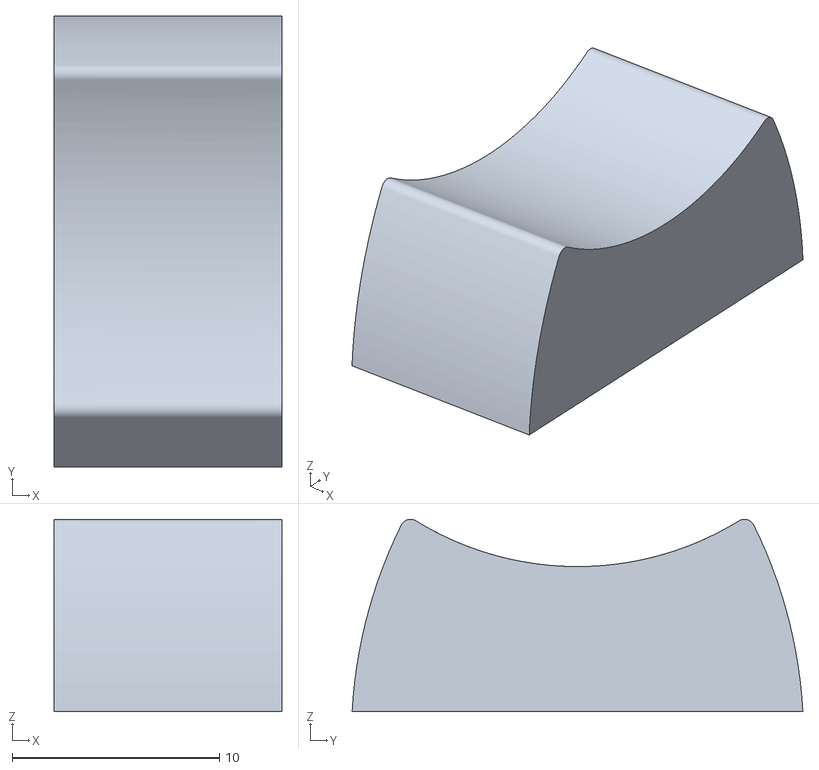
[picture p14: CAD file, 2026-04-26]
hardware/cad/components/fader_knob.stl
11.0 x 21.8 x 9.28

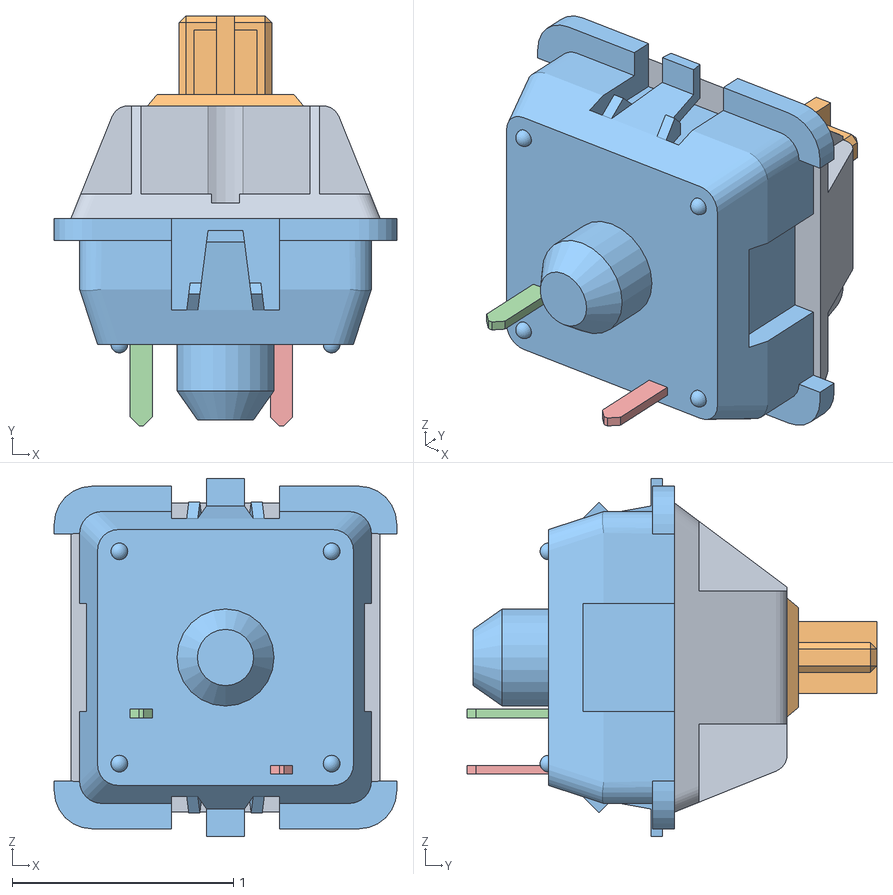
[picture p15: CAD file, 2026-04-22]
hardware/cad/exports/assembly_2026-04-21/cherry mx.obj
1.55 x 1.85 x 1.62
Corps1
Corps2
Corps3
Corps5
Corps6

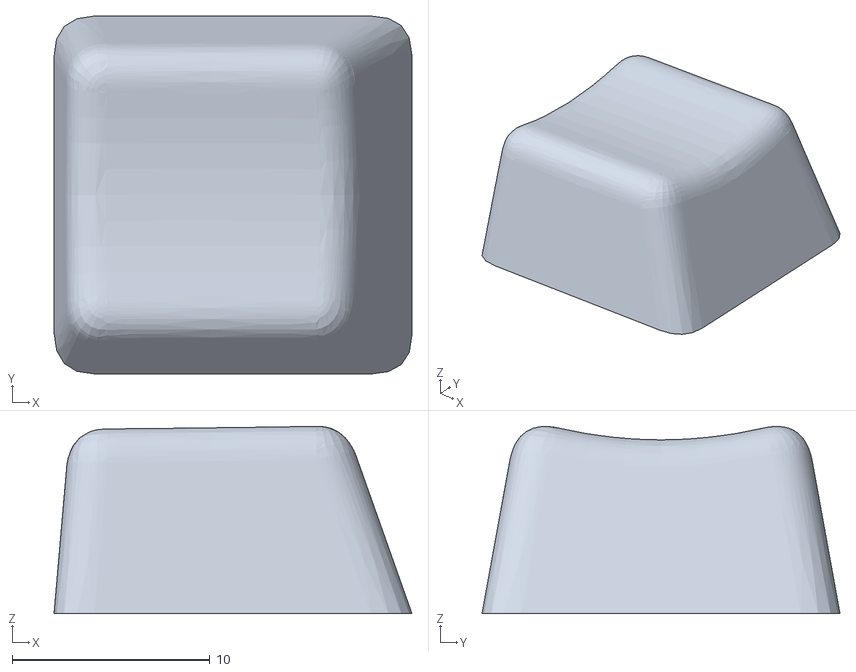
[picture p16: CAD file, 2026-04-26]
hardware/cad/components/cherry_mx_keycap.stl
18.1 x 18.1 x 9.46

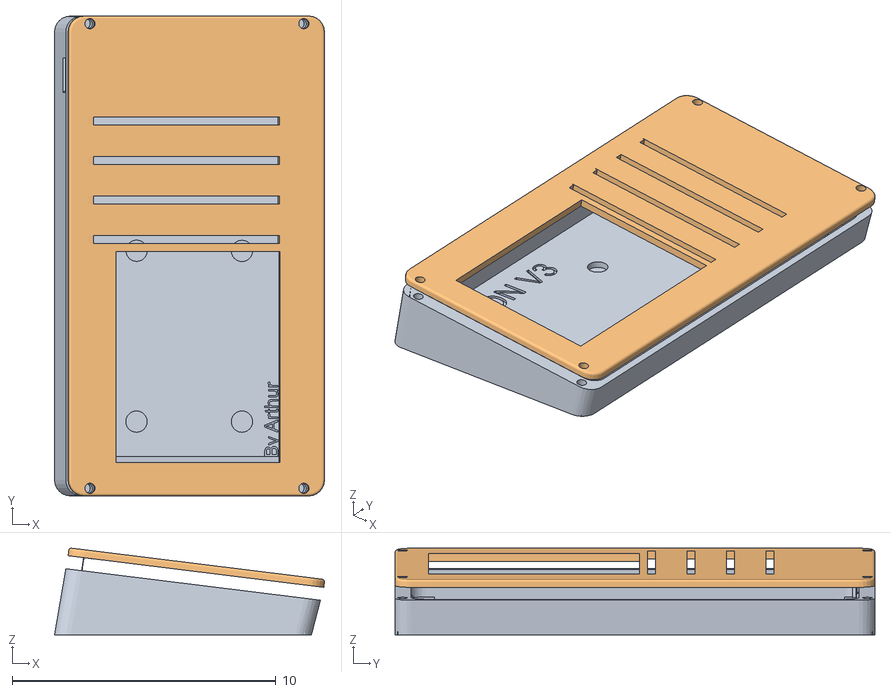
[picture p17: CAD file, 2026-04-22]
hardware/cad/exports/assembly_2026-04-21/bottom.obj
10.2 x 18.2 x 3.29
Corps1
Corps3

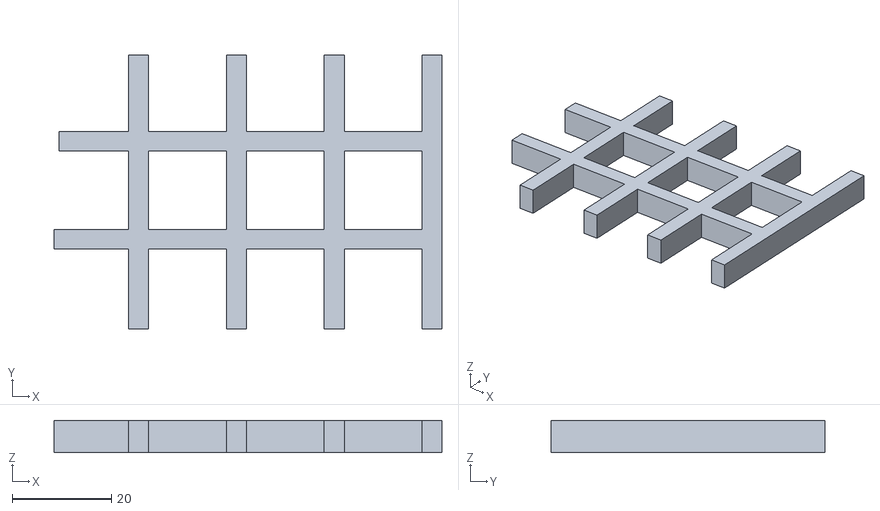
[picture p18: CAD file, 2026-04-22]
hardware/cad/body/alignement des touches.stl
78.0 x 55.0 x 6.50

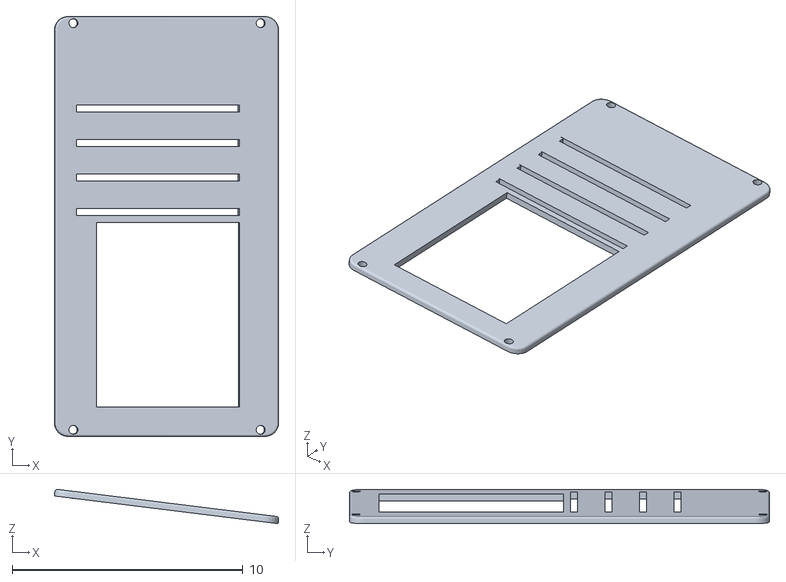
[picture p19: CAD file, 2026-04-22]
hardware/cad/exports/assembly_2026-04-21/top.obj
9.72 x 18.2 x 1.49

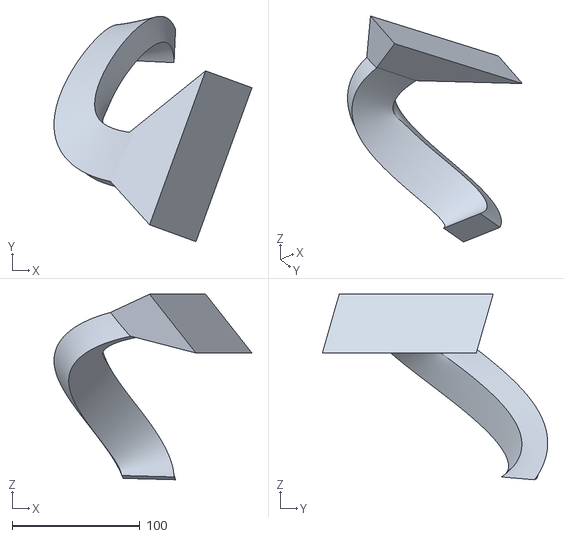
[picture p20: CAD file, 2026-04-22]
hardware/cad/body/tentative bras.stl
154.7 x 176.1 x 145.0

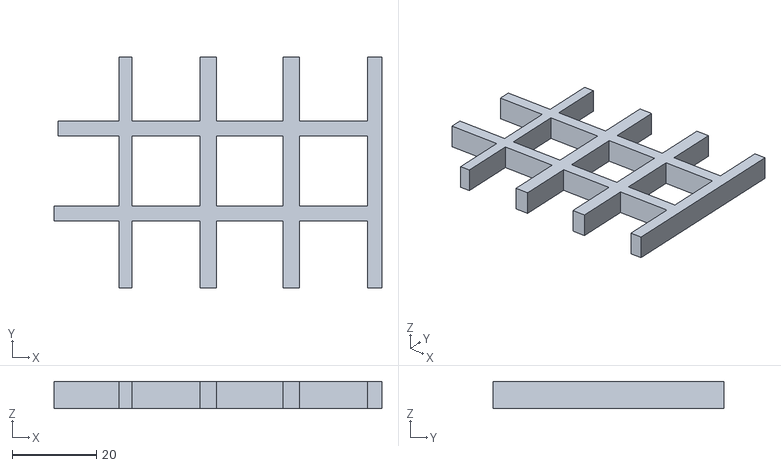
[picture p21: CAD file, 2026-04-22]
hardware/cad/body/alignement des touches_v2.stl
78.0 x 55.0 x 6.50

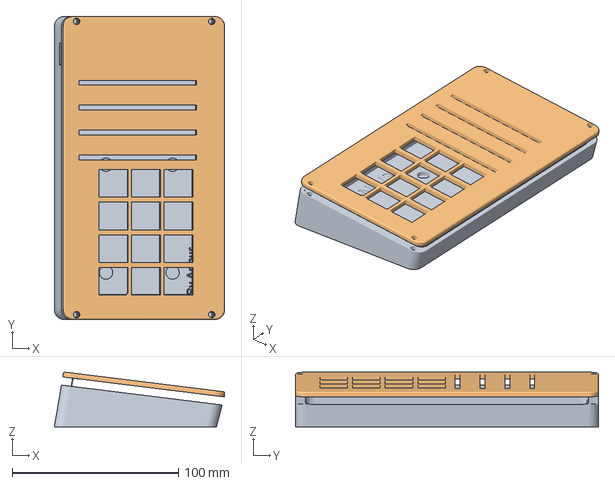
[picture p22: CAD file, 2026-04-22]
hardware/cad/body/body axion v4.3mf
102.4 x 182.0 x 32.9 mm
Corps1
Corps3

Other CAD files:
hardware/cad/body/Body_certo.STL
hardware/cad/components/knob.3mf
hardware/cad/body/Top_Case_.STL
hardware/cad/body/v_perso axion.3mf
_deprecated_root/frontend/public/models/Untitled.blend
frontend/public/models/Untitled.blend
hardware/cad/components/cherry_mx_keycap.obj
hardware/cad/components/fader_knob.obj
hardware/cad/components/screw_chc_m3_l14.obj
website/public/models/Untitled.blend

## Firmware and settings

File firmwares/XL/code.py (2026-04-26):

# ============================================================
#   AXION PAD XL — Firmware v2.0.0
#   16 touches (matrice 4×4), 6 canaux ADC (4 réels + 2 stubs)
#   NeoPixel RGB + OLED SSD1306 128×64
#   Protocole bidirectionnel complet
#
#   Brochage RP2040 :
#     OLED I2C  : SDA=GP0, SCL=GP1
#     Rangées   : GP5 (0), GP6 (1), GP7 (2), GP8 (3)
#     Colonnes  : GP9, GP10, GP11, GP12
#     ADC réels : GP26–GP29  (canaux 0–3)
#     ADC stubs : fixés à 512 (canaux 4–5, futur MCP3208)
#     NeoPixel  : GP13 (16 LEDs)
# ============================================================
import time
import sys
import math
import board
import busio
import digitalio
import analogio
import adafruit_matrixkeypad
import usb_hid
import supervisor
from adafruit_hid.keyboard import Keyboard
from adafruit_hid.keycode import Keycode

DEVICE_ID    = "AXIONPAD:XL"
FIRMWARE_VER = "2.0.0"
NUM_KEYS     = 16
NUM_SLIDERS  = 6

# ── NeoPixel (optionnel) ──────────────────────────────────────
try:
    import neopixel
    pixels = neopixel.NeoPixel(board.GP13, NUM_KEYS, brightness=0.8, auto_write=False)
    HAS_RGB = True
except (ImportError, ValueError, AttributeError):
    HAS_RGB = False

# ── OLED SSD1306 128×64 I2C (optionnel) ──────────────────────
try:
    import adafruit_ssd1306
    _i2c = busio.I2C(board.GP1, board.GP0)
    oled = adafruit_ssd1306.SSD1306_I2C(128, 64, _i2c)
    HAS_OLED = True
except (ImportError, ValueError, OSError, AttributeError):
    HAS_OLED = False

# ── RTC RP2040 (horloge temps réel) ──────────────────────────
try:
    import rtc as _rtc_module
    _rtc = _rtc_module.RTC()
    HAS_RTC = True
except (ImportError, AttributeError):
    HAS_RTC = False

# ── Matrice 4×4 ───────────────────────────────────────────────
rows = [digitalio.DigitalInOut(x) for x in (board.GP5, board.GP6, board.GP7, board.GP8)]
cols = [digitalio.DigitalInOut(x) for x in (board.GP9, board.GP10, board.GP11, board.GP12)]
key_matrix = [[1, 2, 3, 4], [5, 6, 7, 8], [9, 10, 11, 12], [13, 14, 15, 16]]
keypad = adafruit_matrixkeypad.Matrix_Keypad(rows, cols, key_matrix)

# ── ADC (4 réels, 2 stubs) ────────────────────────────────────
real_sliders = [
    analogio.AnalogIn(board.GP26),
    analogio.AnalogIn(board.GP27),
    analogio.AnalogIn(board.GP28),
    analogio.AnalogIn(board.GP29),
]

kbd = Keyboard(usb_hid.devices)

KEY_MAP = {
    0:  [Keycode.F13], 1:  [Keycode.F14], 2:  [Keycode.F15], 3:  [Keycode.F16],
    4:  [Keycode.F17], 5:  [Keycode.F18], 6:  [Keycode.F19], 7:  [Keycode.F20],
    8:  [Keycode.F21], 9:  [Keycode.F22], 10: [Keycode.F23], 11: [Keycode.F24],
    12: [Keycode.APPLICATION], 13: [Keycode.PAUSE],
    14: [Keycode.SCROLL_LOCK], 15: [Keycode.PRINT_SCREEN],
}

# ── État RGB ──────────────────────────────────────────────────
rgb_mode   = "OFF"
rgb_color1 = (124, 58, 237)
rgb_color2 = (0, 120, 255)
rgb_speed  = 80
rgb_bright = 200
rgb_phase  = 0.0

# ── État OLED ─────────────────────────────────────────────────
oled_mode  = "LOGO"    # LOGO | STATS | CLOCK
oled_cpu   = -1
oled_gpu   = -1
oled_ctemp = -1
oled_gtemp = -1
oled_ram   = -1
oled_hhmm  = -1
oled_date  = ""
oled_dirty = True
_oled_tick = 0

# ─────────────────────────────────────────────────────────────
def _parse_color(s):
    p = s.split(",")
    return (int(p[0]), int(p[1]), int(p[2]))

def _scale(color, factor):
    return tuple(max(0, min(255, int(c * factor))) for c in color)

def _update_rgb():
    global rgb_phase
    if not HAS_RGB:
        return
    f = rgb_bright / 255.0
    if rgb_mode == "OFF":
        pixels.fill((0, 0, 0))
        pixels.show()
    elif rgb_mode == "STATIC":
        pixels.fill(_scale(rgb_color1, f))
        pixels.show()
    elif rgb_mode == "BREATHING":
        bv = (math.sin(rgb_phase) + 1.0) / 2.0
        pixels.fill(_scale(rgb_color1, f * bv))
        pixels.show()
        rgb_phase += (rgb_speed / 255.0) * 0.05
        if rgb_phase > 2 * math.pi:
            rgb_phase -= 2 * math.pi
    elif rgb_mode == "WAVE":
        step = (2 * math.pi) / NUM_KEYS
        for i in range(NUM_KEYS):
            t = (math.sin(rgb_phase + i * step) + 1.0) / 2.0
            r = int(rgb_color1[0] * (1 - t) + rgb_color2[0] * t)
            g = int(rgb_color1[1] * (1 - t) + rgb_color2[1] * t)
            b = int(rgb_color1[2] * (1 - t) + rgb_color2[2] * t)
            pixels[i] = _scale((r, g, b), f)
        pixels.show()
        rgb_phase += (rgb_speed / 255.0) * 0.03
        if rgb_phase > 2 * math.pi:
            rgb_phase -= 2 * math.pi

def _update_oled():
    global oled_dirty
    if not HAS_OLED or not oled_dirty:
        return
    oled_dirty = False
    try:
        oled.fill(0)
        if oled_mode == "LOGO":
            oled.text("  AxionPad XL", 0, 8, 1)
            oled.text("  v" + FIRMWARE_VER, 0, 26, 1)
            oled.text("    Ready", 0, 44, 1)
        elif oled_mode == "STATS":
            cpu_s   = ("{}%".format(oled_cpu))   if oled_cpu   >= 0 else "N/A"
            gpu_s   = ("{}%".format(oled_gpu))   if oled_gpu   >= 0 else "N/A"
            ctemp_s = ("{}C".format(oled_ctemp)) if oled_ctemp >= 0 else "N/A"
            gtemp_s = ("{}C".format(oled_gtemp)) if oled_gtemp >= 0 else "N/A"
            ram_s   = ("{}%".format(oled_ram))   if oled_ram   >= 0 else "N/A"
            oled.text("CPU {} T:{}".format(cpu_s, ctemp_s), 0, 0, 1)
            oled.text("GPU {} T:{}".format(gpu_s, gtemp_s), 0, 14, 1)
            oled.text("RAM {}".format(ram_s), 0, 28, 1)
            if oled_hhmm >= 0:
                h = oled_hhmm // 100
                m = oled_hhmm % 100
                oled.text("{:02d}:{:02d}".format(h, m), 44, 48, 1)
        elif oled_mode == "CLOCK":
            if oled_hhmm >= 0:
                h = oled_hhmm // 100
                m = oled_hhmm % 100
                oled.text("   {:02d}:{:02d}".format(h, m), 0, 18, 1)
            if oled_date:
                oled.text("  " + oled_date, 0, 40, 1)
        oled.show()
    except Exception:
        pass  # OLED non câblé ou erreur I2C — ignorer

def _process_command(cmd):
    global rgb_mode, rgb_color1, rgb_color2, rgb_speed, rgb_bright
    global poll_slow, oled_mode, oled_dirty
    global oled_cpu, oled_gpu, oled_ctemp, oled_gtemp, oled_ram
    global oled_hhmm, oled_date

    try:
        if cmd == "POLL:LOW":
            poll_slow = True
        elif cmd == "POLL:HIGH":
            poll_slow = False

        elif cmd.startswith("RGB:"):
            parts = cmd[4:].split(":")
            mode = parts[0]
            if mode == "OFF":
                rgb_mode = "OFF"
            elif mode == "STATIC" and len(parts) >= 2:
                rgb_mode   = "STATIC"
                rgb_color1 = _parse_color(parts[1])
            elif mode == "BREATHING" and len(parts) >= 3:
                rgb_mode   = "BREATHING"
                rgb_color1 = _parse_color(parts[1])
                rgb_speed  = int(parts[2])
            elif mode == "WAVE" and len(parts) >= 4:
                rgb_mode   = "WAVE"
                rgb_color1 = _parse_color(parts[1])
                rgb_color2 = _parse_color(parts[2])
                rgb_speed  = int(parts[3])
            elif mode == "BRIGHT" and len(parts) >= 2:
                rgb_bright = max(0, min(255, int(parts[1])))

        elif cmd.startswith("OLED:"):
            rest = cmd[5:]
            if rest.startswith("MODE:"):
                oled_mode  = rest[5:]
                oled_dirty = True
            else:
                # Format : CPU:75:GPU:62:CTEMP:68:GTEMP:72:RAM:67:HHMM:1430:DATE:25/04
                parts = rest.split(":")
                for i in range(0, len(parts) - 1, 2):
                    key = parts[i]
                    val = parts[i + 1]
                    if   key == "CPU":   oled_cpu   = int(val)
                    elif key == "GPU":   oled_gpu   = int(val)
                    elif key == "CTEMP": oled_ctemp = int(val)
                    elif key == "GTEMP": oled_gtemp = int(val)
                    elif key == "RAM":   oled_ram   = int(val)
                    elif key == "HHMM":  oled_hhmm  = int(val)
                    elif key == "DATE":  oled_date  = val
                oled_dirty = True

        elif cmd.startswith("SYNC:"):
            # SYNC:YYYY:MM:DD:HH:MM:SS
            if HAS_RTC:
                p = cmd[5:].split(":")
                _rtc.datetime = time.struct_time((
                    int(p[0]), int(p[1]), int(p[2]),
                    int(p[3]), int(p[4]), int(p[5]),
                    0, -1, -1))

    except Exception:
        pass

# ── Init ──────────────────────────────────────────────────────
time.sleep(0.5)
print(DEVICE_ID)
print("AXIONPAD:READY")

if HAS_OLED:
    _update_oled()

last_pressed = set()
poll_slow    = False
_cmd_buf     = ""
_adc_tick    = 0

# ─────────────────────────────────────────────────────────────
while True:
    # ── Commandes série entrantes ────────────────────────────
    while supervisor.runtime.serial_bytes_available:
        ch = sys.stdin.read(1)
        if ch in ('\n', '\r'):
            cmd = _cmd_buf.strip()
            _cmd_buf = ""
            if cmd:
                _process_command(cmd)
        else:
            _cmd_buf += ch

    # ── Matrice touches ──────────────────────────────────────
    cur = set(keypad.pressed_keys)
    for k in cur - last_pressed:
        idx = k - 1
        if idx in KEY_MAP:
            kbd.press(*KEY_MAP[idx])
    for k in last_pressed - cur:
        idx = k - 1
        if idx in KEY_MAP:
            kbd.release(*KEY_MAP[idx])
    last_pressed = cur

    # ── ADC : 4 réels + 2 stubs 512 ─────────────────────────
    if not poll_slow or _adc_tick == 0:
        real = [str(int(s.value / 64)) for s in real_sliders]
        print("|".join(real + ["512", "512"]))
    _adc_tick = (_adc_tick + 1) % 200

    # ── Animation RGB ────────────────────────────────────────
    _update_rgb()

    # ── Horloge RTC → mode CLOCK ─────────────────────────────
    if HAS_RTC and HAS_OLED and oled_mode == "CLOCK":
        try:
            now = _rtc.datetime
            oled_hhmm = now.tm_hour * 100 + now.tm_min
            oled_date = "{:02d}/{:02d}".format(now.tm_mday, now.tm_mon)
            oled_dirty = True
        except Exception:
            pass

    # ── Rafraîchissement OLED (toutes les 10 itérations) ────
    _oled_tick = (_oled_tick + 1) % 10
    if _oled_tick == 0:
        _update_oled()

    time.sleep(0.01)

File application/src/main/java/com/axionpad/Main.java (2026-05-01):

package com.axionpad;

import com.axionpad.service.DebugLogger;
import javafx.application.Application;
import java.nio.file.Files;
import java.nio.file.Path;

import java.io.File;
import java.io.FileWriter;
import java.io.IOException;
import java.io.PrintWriter;
import java.time.LocalDateTime;
import java.util.Arrays;

public class Main {

    private static final File LOG = Path.of(System.getProperty("user.home"), ".axionpad", "debug.log").toFile();

    public static void main(String[] args) {
        System.setProperty("prism.order", "sw"); 

        try {
            Files.createDirectories(LOG.getParentFile().toPath());
        } catch (IOException e) {
            System.err.println("Failed to create log directory: " + e.getMessage());
        }

        DebugLogger.log("JVM Started");
        log("java.version        = " + System.getProperty("java.version"));
        log("java.home           = " + System.getProperty("java.home"));
        log("os.arch             = " + System.getProperty("os.arch"));
        log("java.library.path   = " + System.getProperty("java.library.path"));
        log("prism.order         = " + System.getProperty("prism.order"));
        log("args                = " + Arrays.toString(args));
        log(">>> Calling Application.launch() — if the log stops here, JavaFX native init hung");

        try {
            Application.launch(AxionPadApp.class, args);
            log(">>> Application.launch() returned normally — app exited cleanly.");
        } catch (Throwable t) {
            log("FATAL: " + t);
            try (PrintWriter pw = new PrintWriter(new FileWriter(LOG, true))) {
                t.printStackTrace(pw);
            } catch (IOException ignored) {}
            System.exit(1);
        }
    }

    static void log(String msg) {
        LOG.getParentFile().mkdirs();
        try (PrintWriter pw = new PrintWriter(new FileWriter(LOG, true))) {
            pw.println(msg);
        } catch (IOException ignored) {}
    }
}

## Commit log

2026-04-22 Initial release — Axion Pad Configurator
    - JavaFX configurator source (application/)
    - Static landing page for Cloudflare Pages (website/)
    - GitHub Actions auto-deploy workflow
    - Brand assets (SVG logos)
2026-04-22 Nettoyage complet et suppression definitive des fichiers lourds
    [BOM file.xlsx, BOM_AS2040.xlsx, BOM_AXION_V1_PCB_2026-02-24.csv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]
2026-04-22 fix: clear root conflicts to force /website deployment
    Move duplicate /frontend/ (identical to /website/) into /_deprecated_root/
    so Cloudflare Pages has a single unambiguous frontend entry point at /website/.
    [Untitled.blend]
2026-04-22 feat: Stripe checkout with D1 price validation and shipping options
    - src/app/api/checkout/route.ts (edge runtime)
    - POST receives cart items, queries D1 for price+stock before session creation
    - Prevents client-side price tampering — D1 is the source of truth
    - shipping_address_collection for FR/BE/CH/LU/DE/ES/IT/NL/AT/PT
    - Two shipping options: Standard (5.99 €) and Express (12.99 €)
    - To switch to pre-created Stripe rates: replace shipping_rate_data with { shipping_rate: "shr_xxx" }
    - success_url → /success, cancel_url → /shop
    - src/app/success/page.tsx — "Thank you! Your Axion Pad is on the way."
    - src/components/CheckoutButton.tsx — checkout trigger, POSTs to /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
2026-04-22 feat: order tracking via Stripe session lookup
    - src/app/api/track/route.ts (GET ?order=<session_id>&email=<email>)
    - Retrieves Stripe Checkout Session by ID (no D1 required)
    - Uses process.env.STRIPE_SECRET_KEY exclusively
    - 403 if email does not match session.customer_details.email
    - 404 if session ID is invalid
    - Maps payment_status → order status (paid→confirmed, unpaid→pending)
    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
2026-04-22 fix: wire real Stripe checkout — remove Cloudflare adapter dependency
    Root causes:
    1. next.config.ts rewrote ALL /api/* to localhost:3001, so /api/checkout
    and /api/track never reached their Next.js handlers. Changed to
    `fallback` rewrites so Next.js routes take priority.
    2. checkout/route.ts used getRequestContext() (Cloudflare Workers only),
    crashing the handler in the standard Next.js runtime.
    Changes:
    - next.config.ts: rewrites() now returns { fallback: [...] } so
    /api/checkout and /api/track are handled by Next.js; all other
    /api/* paths still proxy to the external API server
    - src/app/api/checkout/route.ts: removed edge runtime and getRequestContext();
    uses process.en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
2026-04-22 Final fix: Edge runtime and Stripe integration verified
    - Add export const runtime = 'edge' to checkout and track API routes
    - Move Stripe initialization inside each handler to prevent build-time
    crash when STRIPE_SECRET_KEY is not available during static generation
2026-04-22 feat: shipping — flat 5.00€ Livraison Standard, single option
    - Set amount to 500 cents (5.00 €) — was 599
    - Remove Express option (add back later if needed)
    - shipping_address_collection already covers FR/BE/CH/LU/DE/ES/IT/NL/AT/PT
    - Stripe adds shipping to the total automatically on its hosted page
2026-04-22 feat: Stripe webhook → D1 orders table
    - Add /api/webhook route (edge runtime) that:
    • verifies Stripe signature with STRIPE_WEBHOOK_SECRET
    • handles checkout.session.completed
    • fetches line items and writes order to D1
    - Add migrations/0001_orders.sql schema (id, order_number, status,
    customer_email/name, amount_total, shipping, items JSON, created_at)
    - Add wrangler.toml with D1 binding (database_id is a placeholder)
    - Update env.d.ts: add STRIPE_WEBHOOK_SECRET to CloudflareEnv
2026-04-22 feat: reviews system, cart CRO, and post-purchase email
    - D1 migration 0002_reviews.sql: reviews table with rating CHECK constraint and product index
    - GET/POST /api/reviews: edge-runtime handlers backed by D1
    - ReviewSection component: interactive star ratings, submission form, verified-buyer badge, optimistic update
    - Product pages: ReviewSection injected below specs/box contents
    - Cart page: stock-aware + button (disabled at max), low-stock badge (< 5 units), free-shipping progress bar, urgency hook, cross-sell of up to 2 in-stock products
    - Webhook: schedules Resend review-request email 7 days after purchase (fire-and-forget, no-op if RESEND_API_KEY unset)
    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
2026-04-23 fix: cart update/remove now apply optimistically to local state
    The /api/cart/items/* routes don't exist, so update() and remove()
    were throwing on every call and leaving the UI frozen. Both now mutate
    Zustand state immediately; the API call runs fire-and-forget so it
    becomes load-bearing once a backend is wired in.
2026-04-23 fix: robust background connection manager for startup auto-connect
    Root cause: on a Windows boot the scheduler was firing at T+2s (before
    USB drivers finished enumerating), latching onto any "USB Serial" device
    via the generic fallback, and then isConnected() returned true forever
    — blocking all subsequent retries even after the real device appeared.
    - startAutoConnect(isStartupLaunch): 12s initial delay on --minimized
    launch gives USB drivers time to enumerate before the first scan
    - scheduleWithFixedDelay replaces scheduleAtFixedRate — next scan starts
    only after the previous one finishes (avoids overlap with the 2.5s
    CircuitPython handshake sleep in connect())
    - Remove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
2026-04-24 Release v1.0.1: Native Protocol, Watchdog, and Branding update
    [AxionPadTest.cfg]
2026-04-24 feat(store): v1.0.1 commercial product availability update
    - Kit PCB seul: corrects PCB spec from 4 layers to 2 layers
    - Axion Pad Pro/Mini/XL: marked comingSoon=true — shows 'Bientôt disponible'
    in configurator and 'En développement' in shop grid; add-to-cart disabled
    - Standard, Kit DIY, Kit PCB seul, Cable, Keycaps remain fully purchasable
    - products-data.ts: adds comingSoon field to ProductVariantFull interface;
    inStock now false for comingSoon products
2026-04-24 feat(website): global branding consistency — DEEJ → AxionPad Native, 4-layer → 2-layer
    About page: PCB card '4 couches' → '2 couches haute stabilité', adds Kailh Hot-swap;
    DEEJ card → 'AxionPad Native' with Watchdog description
    components-data.ts: PCB spec 4→2 couches, switches adds Kailh Hot-swap socket spec
    software/page.tsx: all DEEJ refs → AxionPad Native; features card updated with Native
    Protocol + Power Optimization; mockup title 'Axion Pad Configurator' → 'AxionPad Configurator'
    home page.tsx: DEEJ protocol mention → AxionPad Native
    products.json: Kit DIY PCB spec 4 couches → 2 couches (last remaining instance)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
2026-04-24 Suppression de version CNC
2026-04-26 Mise a jour du model 3d
    [CHC M3 L14.obj, Cherry_Mx_Keycap.obj, Cherry_Mx_Keycap.stl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]
2026-04-26 fix(3d): compress GLB with Draco and remove Blender source files
    axionpad.glb: 33.9MB → 1.8MB (Draco compression)
    Removes .blend/.blend1 from website/public — Cloudflare Pages 25MB limit was exceeded
2026-04-26 chore(cad): reorganize hardware/cad into logical subfolders
    pcb/ — PCB STEP/STP files and Gerber
    components/ — individual parts (keycap, switch, fader knob, screw)
    exports/ — dated OBJ/MTL assembly exports
    body/ — case body source files (unchanged)
    top/ — top panel source files (unchanged)
    Removes redundant ImageToStl.com_ wrappers and extracted zip duplicates.
    [body axion.obj, bottom.obj, cherry mx.obj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]
2026-04-29 fix(ci): replace deprecated pages-action with wrangler-action v3
    - Move @cloudflare/next-on-pages to devDependencies (it's a build tool;
    keeping it in dependencies risked being skipped under --production installs)
    - Switch npm install → npm ci for reproducible, fast CI installs
    - Add npm cache keyed on website/package-lock.json
    - Replace archived cloudflare/pages-action@v1 with cloudflare/wrangler-action@v3
    using `wrangler pages deploy` command — pages-action is unmaintained and
    was the root cause of the 32 s build failure
2026-04-29 fix(ci): break build loop, upgrade to Node 22, use pages:build script
    - Separate `build` (next build) from `pages:build` (next-on-pages) so
    next-on-pages no longer triggers a recursive vercel build invocation
    - Upgrade Node.js from 20 → 22 LTS to silence EBADENGINE warnings from
    camera-controls and other dependencies requiring Node >=22
    - Workflow now calls `npm run pages:build` explicitly, with NODE_VERSION=22
    exported in the build environment
2026-05-01 feat: améliorer la gestion des logs et des volumes Windows
2026-05-01 feat: Corriger les bugs de simulation clavier et mute, nettoyer l'UI média
2026-05-01 refactor: Améliorer la gestion des erreurs et la validation JSON dans OpenRgbServer
2026-05-01 feat: Améliore la gestion des logs et la robustesse du JSON
2026-05-01 refactor: Mettre à jour le logging et la version dans WindowsVolumeService
2026-05-01 fix: Corrige les erreurs de compilation et log dans KeysController
    [Main.java]
2026-05-01 fix: Corriger les appels dbg() restants dans KeysController.java
2026-05-01 docs: Met à jour la documentation avec les changements de la version 2.0.3
2026-05-01 chore: extract website/ to dedicated repo axionpad-website
    Le site Next.js (31 commits) a été migré vers :
    https://github.com/321tutur123/axionpad-website
    Le dossier website/ est retiré du suivi git de ce repo.
    Les fichiers locaux sont conservés.
